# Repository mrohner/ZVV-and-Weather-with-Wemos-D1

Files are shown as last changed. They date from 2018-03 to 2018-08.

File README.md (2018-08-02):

# ZVV-and-Weather
Real Time departure times of Zurich transportation system and weather display with Wemos D1

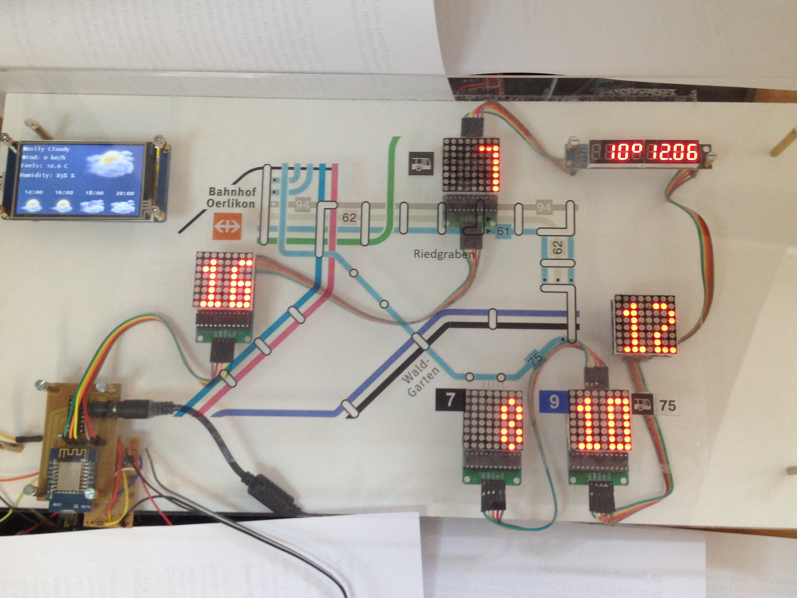
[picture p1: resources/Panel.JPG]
ZVV-and-Weather panel

This panel hangs near my main door for everybody to see the next connections of near by trams, 
buses and trains.
In addition you get a clock, outside temperature as well as weather forecast data.
All the departure times displayed are real time data from the ZVV API and do consider walking times 
to the appropriate station. Departure times are updated every 60 seconds. I have integrated
links to my MQTT system to switch all displays on and off. As well all the data (departure times) are
communicated through MQTT to my home automation system.
See also the video: https://github.com/mrohner/ZVV-and-Weather/blob/master/resources/Panel.mp4)

### Hardware requirements:
* 1 x Wemos D1 mini
* 1 x Nextion display (I used a 3.2 inch model)
* An appropriate number of MAX7219 dot matrix modules (8x8 dots) https://www.aliexpress.com/item/MAX7219-dot-matrix-module-microcontroller-module-display-module-finished-goods/32691592793.html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
* 1 x MAX7219 8-Digit 7 Segment Digital LED Display Tube (the Max7219s are all daisy chained)
* 1 x Power supply 5V 4A
* 1 x SN74HCT125 Quadruple Bus Buffer Gates With 3-State Outputs (basically to convert 3.3V signals
  from the Wemos to 5V signals for the MAX7219
* optional for backlights and movement detection (to save Power after all)
  * 1 x PIR sensor
  * 1 x 2N2222 over a 1K resistor
* a PCB board, plexiglass board

### Contributions:
* [ThingPulse ESP8266 Weather Station] (https://github.com/ThingPulse/esp8266-weather-station)
* [VClouds Weather Icons©] (http://vclouds.deviantart.com/gallery/#/d2ynulp)
* JSON Streaming Parser by Daniel Eichhorn

### ZVV API (unsupported by ZVV though)
http://online.fahrplan.zvv.ch/bin/stboard.exe/dny?input=Z%C3%BCrich,+Riedgraben&dirInput=Zürich,+Hallenbad+Oerlikon&maxJourneys=2&boardType=dep&start=1&tpl=stbResult2json&time=9:32

The names of the stations have to exactly match what you see when using https://online.fahrplan.zvv.ch/bin/query.exe/dn.html

Umlauts have to be represented in the query by i.e ü = %C3%BC (see Wemos_get_ZVV_V2.4.ino)
In this .ino file you find different scenarios such as:
* Dest1 From Zürich,Riedgraben direction to Hallenbad Oerlikon. Walking time to station 6 minutes
There are several bus lines serving this station going pretty much the same way. I'm interseted in 2 connections and take the earliest to display on my panel
(The response from the API is sorted by planned departure time, I'm interested in real departure time thus have to have at least 2 connections and sort by real departure time).
* Dest2 From Zürich,Waldgarten direction to Zürich, Milchbuck. Walking time to station 7 minutes
There are two tram lines going to different places. I'm interested in both. So I ask for 4 connections and take the faster one of each tram line to display.
* Dest3  is similar to case Dest1
* Dest4 Zürich, Oerlikon (SBB) to Zürich HB. I'm interested in a train connection that I can get after having taken the bus (Dest1)
Thus requested departure time of such a train is departure time from Dest1 plus commute time (8 minutes in this case).
I also flag the Inter Regio trains with a dot on the respective Matrix display.

### Nextion Display
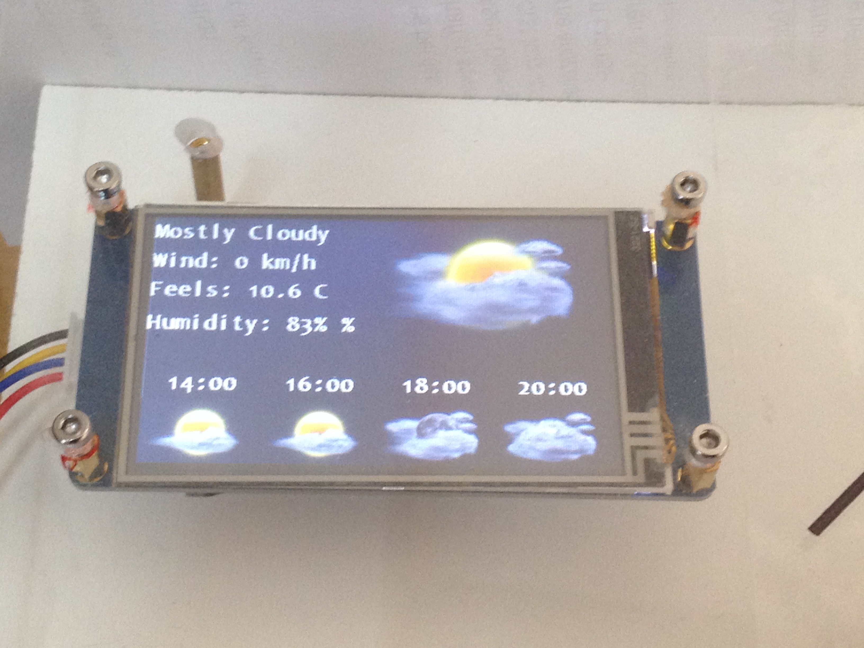
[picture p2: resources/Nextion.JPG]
Nextion display

I check sunset and sunrise time in order to decide which icons to display (the ones with the moon or the sun)
I display current weather conditions (big icon) and 4 forecast icons (smaller icons) for every two hours. e.g. current time is 10:00 you will be able to see forecast for 12:00, 14:00, 16:00 and 18:00. See also my modified NexConfig.h file to allo the Nextion display to be at a softserial port.

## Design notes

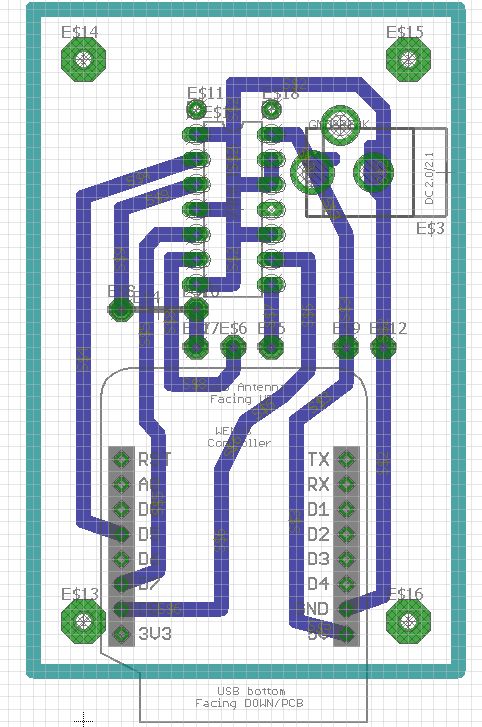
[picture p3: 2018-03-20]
resources/PCB-Pic.jpg

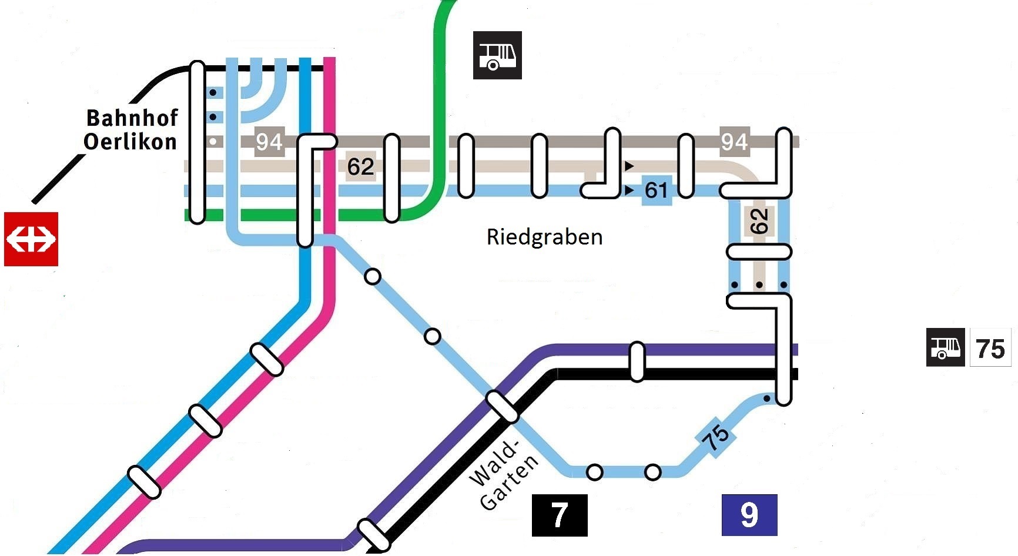
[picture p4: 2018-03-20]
resources/Ausschnitt ZVV plan-1.jpg

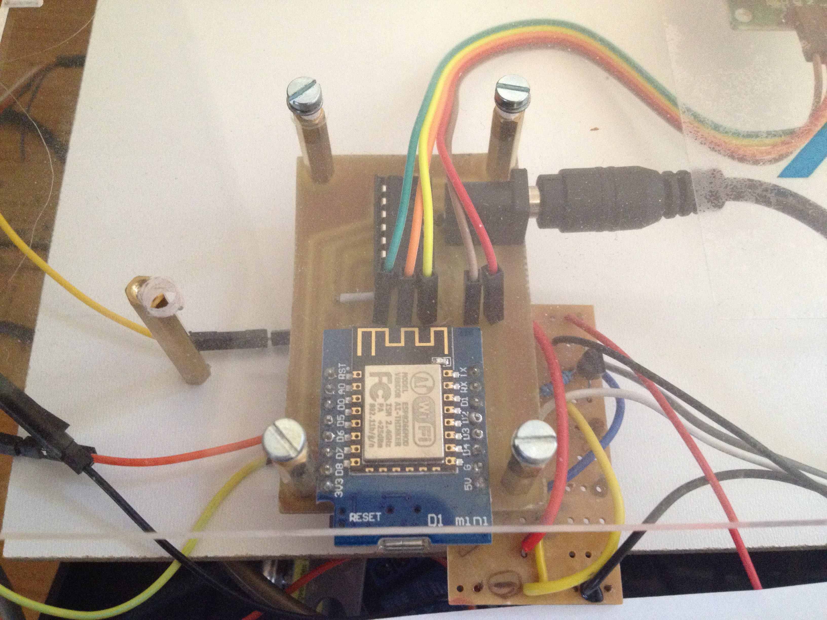
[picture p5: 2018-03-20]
resources/PCB.JPG

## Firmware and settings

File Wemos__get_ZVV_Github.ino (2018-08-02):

/*Pin assignments:
 * Wemos
D0 to TX Nextion
D1 to Base of 2N2222 over a 1K resistor (LEDs)not used
D2 
D4 to RX Nextion
D5 to Pin 2 of SN74HCT125
D7 to Pin 5 of SN74HCT125
D8 to Pin 9 of SN74HCT125

V2.6
Replaced wunderground time with Timelib
- Time is requested from the Linux server through MQTT
Added Syslog facility to log errors etc to the Linux server
Connected to MQTT
- Switch displays off and on 
- sends departure data to MQTT

V2.5
Replaced TimeClient with wunderground time
*/

#include "WundergroundClient.h"
#include <Ticker.h>
#include <JsonListener.h> // I know two JSON libs are an overkill
#include <ArduinoJson.h>  // Just was to lazy to change the code to fit only one.
#include <LedControl.h>
#include <ESP8266WiFi.h>
#include <ESP8266mDNS.h>
#include <WiFiUdp.h>
#include <ArduinoOTA.h>
#include "ZVV.h"
#include "Nextion.h"
#include <TimeLib.h>
#include <Syslog.h>
#include <PubSubClient.h>

SoftwareSerial SoftySerial(16,2); // RX, TX attached to D0, D4 on Wemos D1 mini
NexPage page0    = NexPage(0, 0, "page0");
NexPicture p1 = NexPicture(0, 1, "p1");
NexPicture p2 = NexPicture(0, 2, "p2");
NexPicture p3 = NexPicture(0, 3, "p3");
NexPicture p4 = NexPicture(0, 4, "p4");
NexPicture p5 = NexPicture(0, 5, "p5");
NexText t0 = NexText(0, 6, "t0");
NexText t1 = NexText(0, 7, "t1");
NexText t2 = NexText(0, 8, "t2");
NexText t3 = NexText(0, 9, "t3");
NexText t4 = NexText(0, 10, "t4");
NexText t5 = NexText(0, 11, "t5");
NexText t6 = NexText(0, 12, "t6");
NexText t7 = NexText(0, 13, "t7");
NexTouch *nex_listen_list[] = 
{
    &page0,
    NULL
};

const unsigned char CH[] = { //Font for LED matrices
B00000000, 
B00000000, 
B00000000, 
B00000000, // Space  (represented by "/")

B00000000, 
B11111110, 
B10000010, 
B11111110, // 0

B00000000, 
B10000100, 
B11111110, 
B10000000, // 1

B00000000, 
B11100010, 
B10010010, 
B10001100, // 2

B00000000, 
B10010010, 
B10010010, 
B11111110, // 3

B00000000, 
B00011110, 
B00010000, 
B11111110, // 4

B00000000, 
B10011110, 
B10010010, 
B01110010, // 5

B00000000, 
B11111100, 
B10010010, 
B11110010, // 6

B00000000, 
B00000010, 
B00000010, 
B11111110, // 7

B00000000, 
B01101100, 
B10010010, 
B01101100, // 8

B00000000, 
B10011110, 
B10010010, 
B01111110, // 9
};

// Display settings
int data = 13;    // DIN pin of MAX7219 module
int clk = 14;     // CLK pin of MAX7219 module
int load = 15;    // CS  pin of MAX7219 module
int maxInUse = 6; // how many MAX7219 are connected
LedControl lc=LedControl(data,clk,load,maxInUse); // define Library

// Wireless settings
const char* SSID = "****"; 
const char* PASSWORD = "*****";
int downcount = 0;

//MQTT Settings
const char* mqtt_server = "192.168.178.59";
const char* mqtt_username = "mqtt";
const char* mqtt_password = "****";
char* InTopic = "ZVV/in"; //subscribe to topic to be notified about
char* TimeTopic = "Time"; //subscribe to topic to be notified about
char* OutTopic = "domoticz/in"; 
char* OutTopic1 = "Request/Time"; 
const int SEVEN_IDX = 82;
const int NINE_IDX = 83;
const int SEVENTYFIVE_IDX = 84;
const int BUS_R_IDX = 85;
const int SBB_IDX = 86;
const int ZVV_IDX = 87;

// Syslog server connection info
#define SYSLOG_SERVER "192.168.178.59"
#define SYSLOG_PORT 514
// This device info
#define DEVICE_HOSTNAME "wemos33"
#define APP_NAME "ZVV"
// A UDP instance to let us send and receive packets over UDP
WiFiUDP udpClient;
// Create a new syslog instance with LOG_KERN facility
Syslog syslog(udpClient, SYSLOG_SERVER, SYSLOG_PORT, DEVICE_HOSTNAME, APP_NAME, LOG_KERN);


// ZVV settings
ZVVClient ZVVClient;
String url;
char* Dest1 = "/bin/stboard.exe/dny?input=Z%C3%BCrich,+Riedgraben&dirInput=Z%C3%BCrich,+Hallenbad+Oerlikon&maxJourneys=";
char* Dest1Num ="2"; // Number of connections (Journeys) we are requesting
char* Dest2 = "/bin/stboard.exe/dny?input=Z%C3%BCrich,+Waldgarten&dirInput=Z%C3%BCrich,+Milchbuck&maxJourneys=";
char* Dest2Num ="4";
char* Dest3 = "/bin/stboard.exe/dny?input=Z%C3%BCrich,+Waldgarten&dirInput=Z%C3%BCrich,+Friedackerstrasse&maxJourneys=";
char* Dest3Num ="2";
char* Dest4 = "/bin/stboard.exe/dny?input=Z%C3%BCrich,+Oerlikon+(SBB)&dirInput=Z%C3%BCrich+HB&maxJourneys=";
char* Dest4Num ="7";
//DestxNum cannot be greater than 10, otherwise modify the ZVV.h file
int Number_Journeys;
const char* STARTS = "&boardType=dep&start=1&tpl=stbResult2json&time=";
const int Walking_time_Riedgraben = 6;
const int Walking_time_Waldgarten = 7;
const int Riedgraben_Oerlikon = 8; 
bool IR_train = false; 
int cur_h, cur_m, connection;
int dep_h,dep_m;
int countdown_figure = 0;
int Bus75 = 0;
int BusRiedgraben = 0;
int Tram7 = 0;
int Tram9 = 0;
int TrainOe = 0;

// Timing
volatile int WDTCount = 0;
bool SyncNecessary = true;
time_t prevDisplay = 0; // when the digital clock was displayed
time_t t;
time_t lastMsg = 0;
const int INTERVAL = 600; // 10 mins = 600
bool readyForZVVUpdate = true;
bool readyForWeatherUpdate = true;
bool readyForForecastUpdate = true;
bool readyForSunsetUpdate = true;
Ticker ZVVticker;
Ticker Weatherticker;
Ticker Forecastticker;
Ticker SecondTick; // to stabilize execution
Ticker PublishTick;

// Weather
const boolean IS_METRIC = true;
const String WUNDERGRROUND_API_KEY = "*****";
const String WUNDERGRROUND_LANGUAGE = "EN";
const String WUNDERGROUND_STATION_ID = "IZURICH188";
const String WUNDERGROUND_COUNTRY = "CH";
const String WUNDERGROUND_CITY = "Zurich";
WundergroundClient wunderground(IS_METRIC);

// Light
bool lights_on = true;
bool old_lights_on = true;

WiFiClient espClient;
const int httpPort = 80;
PubSubClient client(espClient);
int counter = 0;


void setup() {
  Serial.begin(9600);
  delay(10);
  Serial.println("Entering Setup");
  for (int i = 0;i < maxInUse;i++){
    lc.shutdown(i,false);
    delay(100);
    // Set the brightness to a medium values 
    lc.setIntensity(i,1);
    delay(100);
    // and clear the display 
    lc.clearDisplay(i);
    delay(100);
  }
  lc.setIntensity(2,5); //Intensity for 7-segment display
  nexInit(); // Initialize Nextion display
  setup_wifi();

  client.setServer(mqtt_server, 8883);
  client.setCallback(callback);
  
  //delay(5000);
  ZVVticker.attach(60, setReadyForZVVUpdate);           // Update every 60 secs
  Weatherticker.attach(481, setReadyForWeatherUpdate);  // Update every 8 minutes
  Forecastticker.attach(1801, setReadyForForecastUpdate); // Update every 30 minutes
  SecondTick.attach(1,ISRwatchdog); //every second
  PublishTick.attach(600,Publish_Status); //every 10 minutes

//OTA
  // Port defaults to 8266
  // ArduinoOTA.setPort(8266);
  // Hostname defaults to esp8266-[ChipID]
  ArduinoOTA.setHostname("Wemos33-ZVV");
  // No authentication by default
  ArduinoOTA.setPassword((const char *)"***");
  ArduinoOTA.onStart([]() {
    Serial.println("Start");
  });
  ArduinoOTA.onEnd([]() {
    Serial.println("\nEnd");
  });
  ArduinoOTA.onProgress([](unsigned int progress, unsigned int total) {
    Serial.printf("Progress: %u%%\r", (progress / (total / 100)));
  });
  ArduinoOTA.onError([](ota_error_t error) {
    Serial.printf("Error[%u]: ", error);
    if (error == OTA_AUTH_ERROR) Serial.println("Auth Failed");
    else if (error == OTA_BEGIN_ERROR) Serial.println("Begin Failed");
    else if (error == OTA_CONNECT_ERROR) Serial.println("Connect Failed");
    else if (error == OTA_RECEIVE_ERROR) Serial.println("Receive Failed");
    else if (error == OTA_END_ERROR) Serial.println("End Failed");
  });
  ArduinoOTA.begin();
    
  Serial.println(F("Entering loop")); 
}


void loop (){
  if (!client.connected()) reconnect();
  if (now() > (t + 82800)) setReadyForClockUpdate();
  nexLoop(nex_listen_list);
  client.loop();
  if (SyncNecessary == false) {
    displayTime();
    if (readyForZVVUpdate) updateZVV();
    wait(1);
    if (readyForSunsetUpdate) updateSunset();
    wait(1);
    if (readyForWeatherUpdate) updateWeather();
    wait(1);
    if (readyForForecastUpdate) updateForecast();
    }
 wait(1);
}


void setup_wifi() {
  WiFi.persistent(false);
  WiFi.mode(WIFI_STA); 
  delay(10);
  // We start by connecting to a WiFi network
  Serial.println();
  Serial.print("Connecting to ");
  Serial.println(SSID);

  WiFi.begin(SSID, PASSWORD);

  while (WiFi.status() != WL_CONNECTED) {
    delay(500);
    Serial.print(".");
  }

  Serial.println("");
  Serial.println("WiFi connected");
  Serial.println("IP address: ");
  Serial.println(WiFi.localIP());
  delay(500);
}


void reconnect() {
  // Loop until we're reconnected
  while (!client.connected()) {
    Serial.print("Attempting MQTT connection...");
    // Attempt to connect
    if (client.connect("ZVVClient",mqtt_username,mqtt_password)) {
      Serial.println("connected");
      counter = 0;
      // Once connected, publish an announcement...
      // ... and resubscribe
      client.subscribe(InTopic);
      delay(10);
      client.subscribe(TimeTopic);
      client.publish(OutTopic1,"1");
      delay(10);
      Publish_Status();
    } else {
      Serial.print("failed, rc=");
      Serial.print(client.state());
      Serial.println(" try again in .3 seconds");
      ++counter;
      if (counter > 180) ESP.reset();
      // Wait 0.3 seconds before retrying
      ArduinoOTA.handle();
      wait(300);
    }
  }
}


void callback(char* topic, byte* payload, unsigned int length) {
  StaticJsonBuffer<500> jsonBuffer;
  JsonObject& root = jsonBuffer.parseObject((char*)payload);
    int idx = root["idx"]; // 34
    int nvalue = root["nvalue"]; // request: 0 = open, 1 = closed
    int day_from_system = root["day"]; // 9
    int month_from_system = root["month"]; // 11
    int year_from_system = root["year"]; // 2017
    int hour_from_system = root["hour"]; // 16
    int minutes_from_system = root["minutes"]; // 29
    int seconds_from_system = root["seconds"]; // 26

    String what = String(nvalue);
    if (day_from_system && SyncNecessary || timeStatus() == timeNotSet) {
      setTime(hour_from_system,minutes_from_system,seconds_from_system,day_from_system,month_from_system,year_from_system); // alternative to above, yr is 2 or 4 digit yr
      Serial.println(F("Setting Time"));
      SyncNecessary = false;
      t = now();
      do wait(1);          // wait for clock to be at 0 secs
      while (second() != 0);
      }
    if (idx == ZVV_IDX) {
      if (nvalue == 1) light_on();
      else light_off();
      if (lights_on != old_lights_on) {
        publish(ZVV_IDX,lights_on,0);
        old_lights_on = lights_on;
      }
    }
}  


void updateZVV() {
 int trams_found = 0;
 int last_tram = 0;
 int tint = 0;
 int i = -1;
 Serial.println(F("------------------------------------------------------------------------------"));
 // Departure Waldgarten Bus75
 depart(Walking_time_Waldgarten, Dest3, Dest3Num);
 Serial.println("Bus: 75");
 ZVVClient.doUpdate(url);
 countdown_figure = ZVVClient.getCountdown(0);
 Serial.print(F("countdown: "));
 Serial.println(countdown_figure);
 Serial.println();
 if (Bus75 != countdown_figure) {
  Bus75 = countdown_figure;
  publish(SEVENTYFIVE_IDX,0,Bus75);
 }
 displayChar(countdown_figure,3);

 // Departure Riedgraben Buses
 depart(Walking_time_Riedgraben, Dest1, Dest1Num);
 Serial.println(F("Bus Riedgraben:"));
 ZVVClient.doUpdate(url);
 countdown_figure = ZVVClient.getCountdown(0);
 Serial.print(F("countdown: "));
 Serial.println(countdown_figure);
 Serial.println();
 connection = countdown_figure;
 if (BusRiedgraben != countdown_figure) {
  BusRiedgraben = countdown_figure;
  publish(BUS_R_IDX,0,BusRiedgraben);
 }
 displayChar(countdown_figure,1);

// Departure Oerlikon SBB
 if (connection < Walking_time_Riedgraben) connection = Walking_time_Riedgraben;
 depart(connection+Riedgraben_Oerlikon, Dest4, Dest4Num);
 Serial.println(F("Trains Oerlikon:"));
 ZVVClient.doUpdate(url);
 do {
   i++;
   tint = ZVVClient.getType(i);
   if (tint == 5 || tint == 1) { //check if it is a S-Bahn (type 5) or InterRegio (type 1)
     Serial.print("type: "); 
     Serial.println(tint);
     Serial.print(F("countdown: "));
     Serial.println(ZVVClient.getCountdown(i));
     Serial.println();
     trams_found++; 
     if (tint == 1) IR_train = true;
     } 
   } while (trams_found < 1 && i < Number_Journeys -1);
 displayChar(ZVVClient.getCountdown(i),0);
 if (TrainOe != ZVVClient.getCountdown(i)) {
   TrainOe = ZVVClient.getCountdown(i);
   publish(SBB_IDX,0,TrainOe);
   }
 IR_train = false;
 i = -1;
 trams_found = 0;

 // Departure Waldgarten Trams
 depart(Walking_time_Waldgarten, Dest2, Dest2Num);
 Serial.println(F("Trams Waldgarten:"));
 ZVVClient.doUpdate(url);
 do {
   i++;
   tint = (ZVVClient.getLine(i)).toInt();
   if (last_tram != tint) {
     Serial.print("Trm: "); 
     Serial.println(tint);
     Serial.print(F("countdown: "));
     Serial.println(ZVVClient.getCountdown(i));
     if (tint == 7) { 
      displayChar(ZVVClient.getCountdown(i),5);
      if (Tram7 != ZVVClient.getCountdown(i)) {
        Tram7 = ZVVClient.getCountdown(i);
        publish(SEVEN_IDX,0,Tram7);
      }
     }
     else {
      displayChar(ZVVClient.getCountdown(i),4);
      if (Tram9 != ZVVClient.getCountdown(i)) {
        Tram9 = ZVVClient.getCountdown(i);
        publish(NINE_IDX,0,Tram9);
      }
     }
     last_tram = tint;
     trams_found++;
     }
   } while (trams_found < 2 && i < Number_Journeys -1);
   i = -1;
   last_tram = 0;
   trams_found = 0;
        
 readyForZVVUpdate = false;  
}


void depart(int walking_time, char* Dest, char* Num){
  String dep_time = "";
  Number_Journeys = atoi(Num);
  dep_h = hour();
  dep_m = minute()+walking_time;
  if(dep_m >= 60){
    dep_m =  dep_m % 60;
    dep_h++;
  }
  if (hour() == 24 && dep_h == 24) dep_h = 0;
  if (dep_h < 10) dep_time = "0";
  dep_time += String(dep_h) + ":";
  if (dep_m < 10) dep_time += "0";
  dep_time += String(dep_m);
  Serial.println(dep_time);
  url = Dest;
  url += Num;
  url += STARTS;
  url += dep_time;
}


void displayChar(int departure_time, int display_Matrix_Number){
  byte dot = B00000000;
  int char_val;
  String c = String(departure_time);
  lc.clearDisplay(display_Matrix_Number);
  int str_len = c.length() + 1; 
   if (str_len == 1 || str_len > 3) {
    c="//";
    str_len = 3;
   }
  // Prepare the character array (the buffer) 
  char char_array[str_len];
  // Copy it over 
  c.toCharArray(char_array, str_len);
  if (str_len == 3){ //swap digits
    char tt = char_array [0];
    char_array[0] = char_array [1];
    char_array[1]= tt; 
   }
  if(IR_train) dot = B00000001;
  for (int i=str_len-2;i>-1;i--){
  if (char_array[i] < 47) return;
    //Serial.print("C: ");
    char_val = char_array[i]-47;
    //Serial.println(char_val);
    for (int j=0;j<4;j++){
      lc.setRow(display_Matrix_Number,4-4*i+j,(CH[4*char_val+j]) | dot); // add a dot to indicate the type 1 train (IR)
      IR_train = false;
      dot = B00000000;
     }
   }
  yield();
}


void displayTime() {
  lc.setChar(2,0,minute()%10,false); //Display minutes
  lc.setChar(2,1,minute()/10,false);
  lc.setChar(2,2,hour()%10,true);
  if (hour() > 9) lc.setChar(2,3,hour()/10,false);
  else lc.setChar(2,3,' ',false);
}


void setReadyForClockUpdate() {
  SyncNecessary = true;  
}

void setReadyForZVVUpdate() {
  readyForZVVUpdate = true;  
}

void setReadyForWeatherUpdate() {
  readyForWeatherUpdate = true;  
}


void updateWeather() {
  wunderground.updateConditions(WUNDERGRROUND_API_KEY, WUNDERGRROUND_LANGUAGE, WUNDERGROUND_STATION_ID);
  if (hour() == 1 && minute() < 12) readyForSunsetUpdate = true;
  displayTemp();
  displayWeather();
  readyForWeatherUpdate = false;
}


void displayTemp() {
  String temp = wunderground.getCurrentTemp();
  Serial.println(temp);
  lc.setRow(2,4,B01100011); // degree sign on segment 4
  for (int i = 5;i < 8;i++){
    lc.setChar(2,i,' ',false); 
  }
  int str_len = temp.length();
  Serial.println(str_len);
  int segment = 4;
  for (int i = str_len-3;i>-1;i--){// - x020
    segment++;
    lc.setChar(2,segment,temp[i],false);
  }
}


void displayWeather() {
  t0.setText(wunderground.getWeatherText().c_str());
  t1.setText(wunderground.getWindSpeed().c_str());
  t2.setText(wunderground.getFeelsLike().c_str());
  t3.setText(wunderground.getHumidity().substring(0,13).c_str());
  String modified_IconText = "";
  Serial.print("sunrise: ");
  Serial.println(wunderground.getSunriseTime());
  Serial.print("sunset: ");
  Serial.println(wunderground.getSunsetTime());
  if (!isDay(hour(),wunderground.getSunriseTime().toInt(),wunderground.getSunsetTime().toInt())) {
    modified_IconText = "nt_" + wunderground.getTodayIconText();
  }
  else modified_IconText = wunderground.getTodayIconText();
  p1.setPic(wunderground.getMeteoconIcon(modified_IconText));
  yield();
}


void setReadyForForecastUpdate() {
  readyForForecastUpdate = true;  
}


void updateForecast() {
 wunderground.updateHourlyForecast(WUNDERGRROUND_API_KEY, WUNDERGRROUND_LANGUAGE, WUNDERGROUND_COUNTRY, WUNDERGROUND_CITY);
 displayForecast();
  readyForForecastUpdate = false;
}


void displayForecast() {
  for (int i = 1;i < 9; i += 2) {
    String modified_IconText = "";
    String modified_hour="";
    if (!isDay(wunderground.getHourlyForecastHour(i).toInt(),wunderground.getSunriseTime().toInt(),wunderground.getSunsetTime().toInt())) {
      modified_IconText = "nt_" + wunderground.getHourlyForecastIcon(i);
    }
    else modified_IconText = wunderground.getHourlyForecastIcon(i);
    if (wunderground.getHourlyForecastHour(i).toInt() < 10) modified_hour += "0";
    modified_hour += wunderground.getHourlyForecastHour(i);
    modified_hour += ":00";
    Serial.print(i);
    Serial.print(modified_IconText);
    Serial.println(modified_hour);
    switch (i) {
    case 1: {
      p2.setPic(26 + wunderground.getMeteoconIcon(modified_IconText));
      t4.setText(modified_hour.c_str()); 
      }
      break;
    case 3: {
      p3.setPic(26 + wunderground.getMeteoconIcon(modified_IconText));
      t5.setText(modified_hour.c_str()); 
      }
      break;
    case 5: {
      p4.setPic(26 + wunderground.getMeteoconIcon(modified_IconText));
      t6.setText(modified_hour.c_str()); 
      }
      break;
    case 7: {
      p5.setPic(26 + wunderground.getMeteoconIcon(modified_IconText));
      t7.setText(modified_hour.c_str()); 
      }
      break;
    }
  }
}


void ISRwatchdog() {
  WDTCount++;
  if (WDTCount == 25) ESP.reset();
}


void light_off() {
  yield();
  for (int i = 0;i < maxInUse;i++){
    lc.shutdown(i,true);
    wait(100);
   }
  nexSerial.print("dim=0");
  nexSerial.write(0xff);
  nexSerial.write(0xff);
  nexSerial.write(0xff);
  lights_on = false;
  }


void light_on() {
  for (int i = 0;i < maxInUse;i++){
    lc.shutdown(i,false);
    wait(100);
  }
  nexSerial.print("dim=80");
  nexSerial.write(0xff);
  nexSerial.write(0xff);
  nexSerial.write(0xff);
  lights_on = true;
  }


void updateSunset() {
  wunderground.updateAstronomy(WUNDERGRROUND_API_KEY, WUNDERGRROUND_LANGUAGE, WUNDERGROUND_COUNTRY, WUNDERGROUND_CITY);
  readyForSunsetUpdate = false;  
}

bool isDay (int current, int sun_rise, int sun_set) {
return (current < 23 && current > 4 && current < sun_set && current > sun_rise);
}


//{"idx":29,"nvalue":0,"svalue":"123"}
void publish(int idx, int nvalue, int svalue){ 
  char output[130];
  snprintf_P(output, sizeof(output), PSTR("{\"idx\":%d,\"nvalue\":%d,\"svalue\":\"%d\"}"),idx,nvalue,svalue);
  client.publish(OutTopic,output);
  String log_output;
  log_output = output;
  syslog.logf(LOG_INFO, "%s", log_output.c_str());
}


void Publish_Status() {
  publish(ZVV_IDX,lights_on,0);
  old_lights_on = lights_on; 
}


void wait (int ms) {
  for(long i = 0;i <= ms * 30000; i++) asm ( "nop \n" ); //80kHz Wemos D1
  ArduinoOTA.handle();
  yield();
  WDTCount = 0;
}

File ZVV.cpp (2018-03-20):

#include <ESP8266WiFi.h>
#include <WiFiClient.h>
#include "ZVV.h"

ZVVClient::ZVVClient() {
}

void ZVVClient::doUpdate(String url) {
  JsonStreamingParser parser;
  parser.setListener(this);
  WiFiClient client;
  int downcount = 0;
  const int httpPort = 80;
  if (!client.connect("online.fahrplan.zvv.ch", httpPort)) {
    Serial.println("connection failed");
    Serial.println("wait 3 sec...");
    downcount++;
    if (downcount > 3) {
      downcount = 0;
      ESP.restart();
      }  
    delay(3000);
    return;
  }
  Serial.print("Requesting URL: ");
  Serial.println(url);
  // This will send the request to the server
  client.print(String("GET ") + url + " HTTP/1.1\r\n" +
               "Host: online.fahrplan.zvv.ch\r\n" +
               "Connection: close\r\n\r\n");
  int retryCounter = 0;
  while(!client.available()) {
    delay(1000);
    retryCounter++;
    if (retryCounter > 10) {
      ESP.restart();
    }
  }
  int pos = 0;
  boolean isBody = false;
  char c;
  int size = 0;
  client.setNoDelay(false);
  while(client.connected()) {
    while((size = client.available()) > 0) {
      c = client.read();
      if (c == '{' || c == '[') {
        isBody = true;
      }
      if (isBody) {
        parser.parse(c);
      }
    }
  }
}

void ZVVClient::whitespace(char c) {
  //Serial.println("whitespace");
}

void ZVVClient::startDocument() {
  //Serial.println("start document");
  count = -1;
}

void ZVVClient::key(String key) {
currentKey = String(key);
}

void ZVVClient::value(String value) {
  //Serial.print(currentParent[hierarchy_level]);
  //Serial.print("   ");
  //Serial.println(currentKey);
    if (currentParent[hierarchy_level] == "product") {  // Has a Parent key and 2 sub-keys
      if (currentKey == "type") {
        count++;
        //Serial.println(count);
        ZVVReadings[count].type = value.toInt();
        //Serial.println(value.toInt());
        }
      if (currentKey == "line") {
        ZVVReadings[count].line = value;
        //Serial.println(value);
        }
      if (currentKey == "direction") {
        ZVVReadings[count].direction_to = value;
        }
    }
    if (currentParent[hierarchy_level] == "mainLocation" && currentKey == "countdown") {
      ZVVReadings[count].a_countdown  = value.toInt();
      //Serial.println(value.toInt());
      }
      if (currentParent[hierarchy_level-1] == "mainLocation" && currentParent[hierarchy_level] == "realTime" && currentKey == "countdown") { 
      ZVVReadings[count].countdown = value.toInt();
        if (ZVVReadings[count].countdown == 0) ZVVReadings[count].countdown = ZVVReadings[count].a_countdown;
      //Serial.println(ZVVReadings[count].countdown);
    }
 }

void ZVVClient::endArray() {
}


void ZVVClient::startObject() {
  hierarchy_level++;
  currentParent[hierarchy_level] = currentKey;
}

void ZVVClient::endObject() {
  hierarchy_level--;
}

void ZVVClient::endDocument() {
sortZVVreadings();
  for (int i = 0; i < count+1;i++){
    Serial.print(F("ZVV "));
    Serial.print(ZVVReadings[i].type);
    Serial.print(F("   "));
    Serial.print(ZVVReadings[i].line);
    Serial.print(F("   "));
    Serial.print(ZVVReadings[i].a_countdown);
    Serial.print(F("   "));
    Serial.print(ZVVReadings[i].countdown);
    Serial.print(F("   "));
    Serial.println(ZVVReadings[i].direction_to);
    }
}

void ZVVClient::startArray() {
}


void ZVVClient::sortZVVreadings()
{
    bool swapped;
    ZVVReading temp;

    do
    {
        swapped = false;
        for (byte i = 0; i != count; ++i)
        {
            if (ZVVReadings[i].countdown > ZVVReadings[i+1].countdown)
            {
                temp = ZVVReadings[i];
                ZVVReadings[i] = ZVVReadings[i + 1];
                ZVVReadings[i + 1] = temp;
                swapped = true;
            }
        }
    } while (swapped);
}


int ZVVClient::getType(int i) {
  return ZVVReadings[i].type;
}
String ZVVClient::getLine(int i) {
  return ZVVReadings[i].line;
}
int ZVVClient::getCountdown(int i) {
  return ZVVReadings[i].countdown;
}
String ZVVClient::getDirection(int i) {
  return ZVVReadings[i].direction_to;
}
